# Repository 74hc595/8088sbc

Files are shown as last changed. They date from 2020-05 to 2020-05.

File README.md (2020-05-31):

# 8088 Single Board Computer

A minimal single-board computer based on the Intel 8088 processor.
That's the same processor used in the original IBM PC, but this is just a
simple project and doesn't strive for PC/DOS compatibility.



## Specs
- 8088 or compatible CPU in minimal mode (5 MHz with [8088](https://www.jameco.com/z/8088-Major-Brands-IC-8088-8-Bit-HMOS-MPU_52142.html), 8 MHz with 8088-2)
    - Clock oscillator at 3x frequency of CPU clock frequency. For 8 MHz operation, uses a [24 MHz half-can crystal oscillator](https://www.mouser.com/ProductDetail/ECS/ECS-2200B-240?qs=GxOUx7aO6nwQDraMtk%2FyHw%3D%3D)
- 1 MB static RAM (2x [AS6C4008-55PCN](https://www.mouser.com/ProductDetail/Alliance-Memory/AS6C4008-55PCN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))
- 32 KB ROM (1x [AT28C256-15](https://www.jameco.com/z/28C256-15-Major-Brands-IC-28C256-16-EEPROM-256K-Bit-CMOS-Parallel_74843.html))
- FTDI-compatible 5V serial port provided by a [16C550](https://www.jameco.com/shop/ProductDisplay?catalogId=10001&langId=-1&storeId=10001&productId=288809) UART (up to 115200 baud)
- 32 column by 4 row LED display (sixteen PDSP-1881 intelligent displays,
  display board schematic available [here](https://github.com/74hc595/kicad-intelligent-displays))
- Uses five common 74HC chips for glue logic (74HC4017, 74HC132, 74HC573,
  74HC75, 74HC139). Does not require any of the Intel 8200-series support chips.
- 5V power via USB-A connector

## Memory map

```
00000h-7FFFFh - RAM
80000h-FFFFFh - bankable (RAM, ROM, expansion 1, or expansion 2)
```

## I/O map

Only bits 7 and 8 are used for decoding.

```
000h-07Fh - I/O bank 0
    060h-067h - 16550 UART
080h-0FFh - I/O bank 1
100h-17Fh - I/O bank 2
    100h-107h - 128-character display (16x PDSP-1881 or similar)
180h-1FFh - I/O bank 3
```

More info on display decoding:

```
100h-17Fh - Flash RAM
900h-97Fh - UDC Address Register
B00h-B7Fh - UDC RAM
D00h-D7Fh - Control Word Register
F00h-F7Fh - Character RAM
```

## Bank switching and input/output

The modem control lines of the 16550 UART are used as general purpose input and
output lines.

```
~OUT1 - bank select bit 0
~OUT2 - bank select bit 1
~DTR  - general purpose output 0 (LED2)
~RTS  - general purpose output 1 (LED3)
~RI   - general purpose input 0
~DCD  - general purpose input 1
~DSR  - general purpose input 2
~CTS  - general purpose input 3
```

Bank select bits 0 and 1 control which device is mapped into the upper half of
the address space:

```
00 - expansion 1
01 - expansion 2
10 - RAM
11 - ROM (default at power-up)
```

These are controlled by bits 2 and 3 of the 16550's Modem Control Register.
(`64h`)

## Interrupts

The four general-purpose inputs can be set up as inputs by configuring the
16550's Interrupt Enable Register (`61h`). However, this won't be very useful
because the 8088's `~INTA` line is not connected to anything, so when an
interrupt is received, there is no device to place the vector number on the data
bus.

Pressing the `NMI` button will generate a non-maskable interrupt (`INT 04h`).
The button is debounced in hardware.

## Software

Not much here, just enough to test memory and dump the register state. Compiles
with NASM (version 2.14.02 used). Running `make` in the `code/` directory
generates as 32KB binary file. Running `make flash` can be used to burn the
ROM image to an AT28C256 EEPROM chip using a [MiniPro TL866II+](https://www.amazon.com/tl866ii-plus/s?k=tl866ii+plus)
with the [minipro](https://gitlab.com/DavidGriffith/minipro/) utility.

(The TL866II+ is around $60 USD and widely available, if you don't have one,
you should get one!)

1. Power LED will light up.
2. `OUT1` LED will blink four times. (Testing 8 segments of lower RAM)
3. `OUT0` will light.
4. `OUT1` LED will blink four times. (Testing 8 segments of upper RAM)
5. `Hello 8088!` will be printed to the serial port. (115200 8N1)
6. `OUT0` and `OUT1` LEDs will toggle with 50% duty cycle. (verify with scope)
7. Pressing the `NMI` button will print the register state:

```
AX=F001 CS=F000 IP=82E0      NMI
BX=FFF0 DS=F000 SI=82F5     --I-
CX=0000 ES=0000 DI=0024 --------
DX=F202 SS=7000 SP=FFE6 BP=FFFF
```

### API

Interrupt vector `06h` points to the character output routine. If using the
PDSP-1881 LED display, this can be changed to `disp_outch_int` to write to the
display instead of the serial port.

`INT 07h` prints the null-terminated string in `CS:SI`.

`INT 08h` is a rudimentary formatted-output routine. See `output.inc`.

## Future work

Probably none. This was just a quick project and I probably won't work on it
long-term because... honestly, I'm just not a fan of 8086 assembly language and
its weird 16-bit segmented model. Mainly, I had these chips lying around and
wanted to do something with them.

## About

Open hardware, released under the terms of the 3-clause BSD license.

Copyright 2020 Matt Sarnoff.

http://twitter.com/txsector

http://msarnoff.org

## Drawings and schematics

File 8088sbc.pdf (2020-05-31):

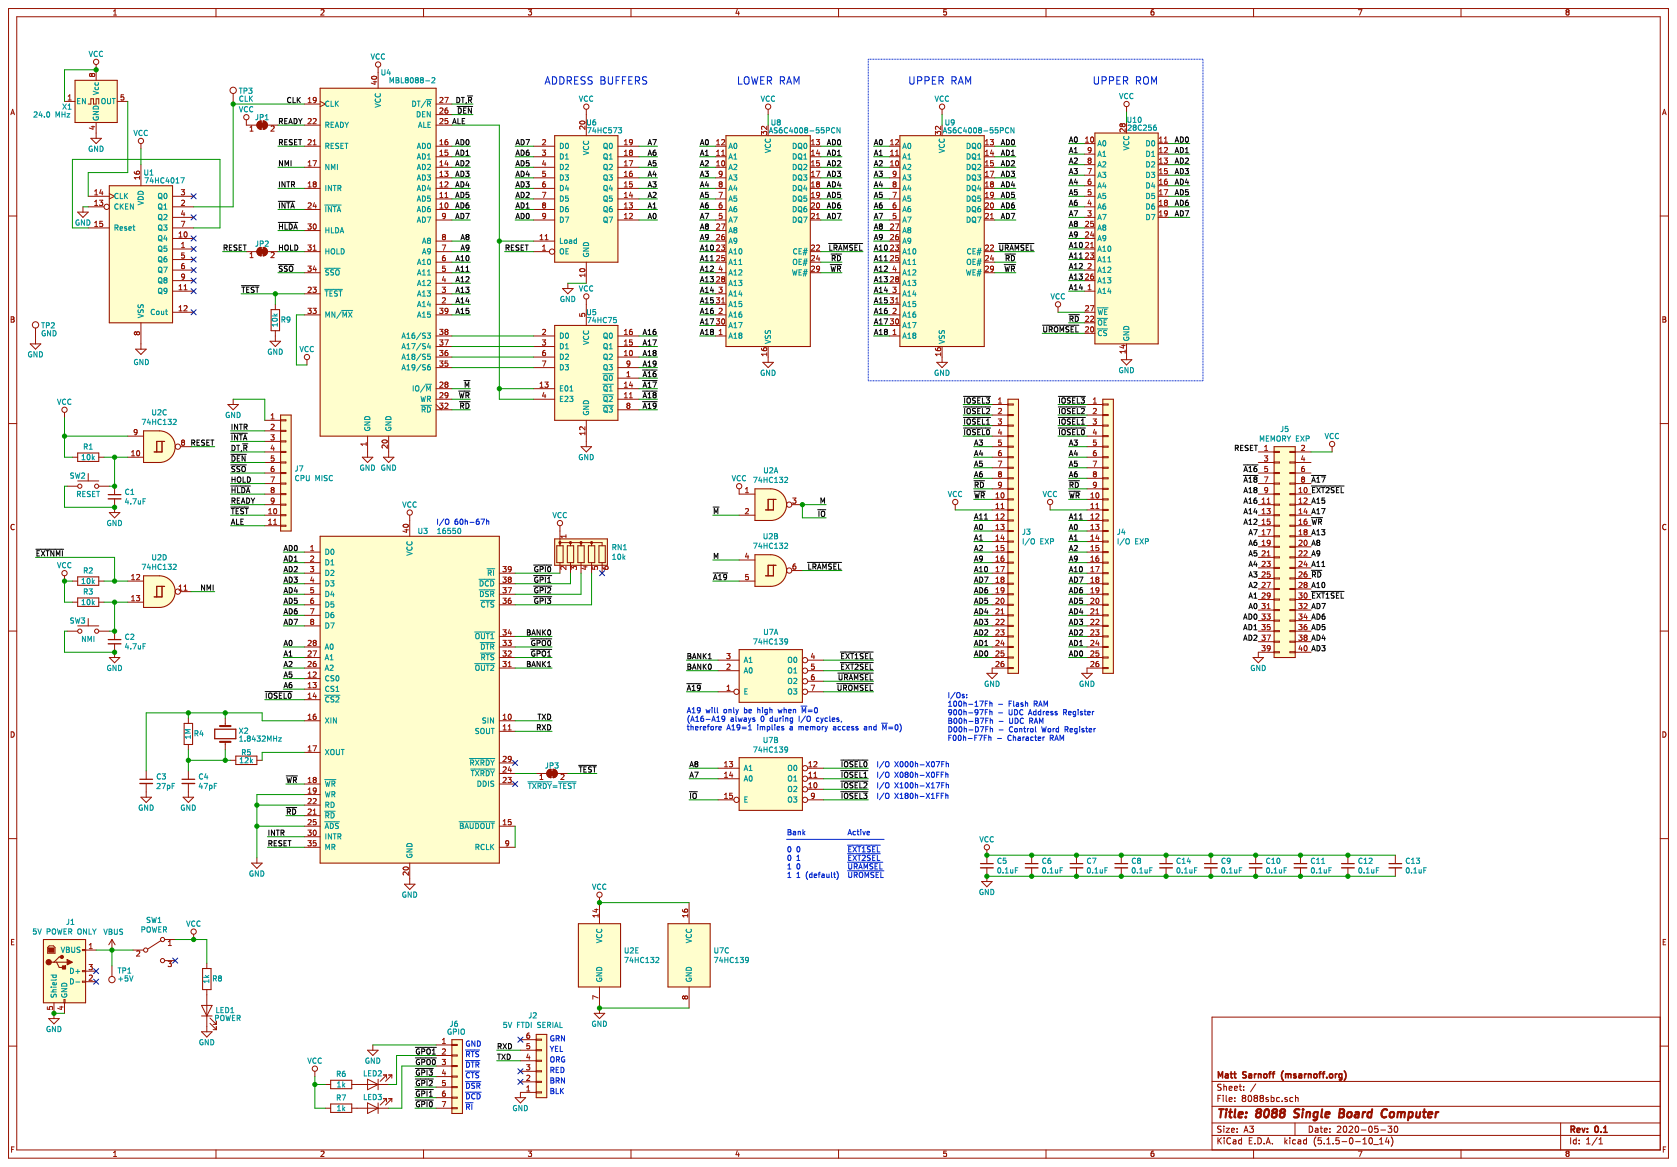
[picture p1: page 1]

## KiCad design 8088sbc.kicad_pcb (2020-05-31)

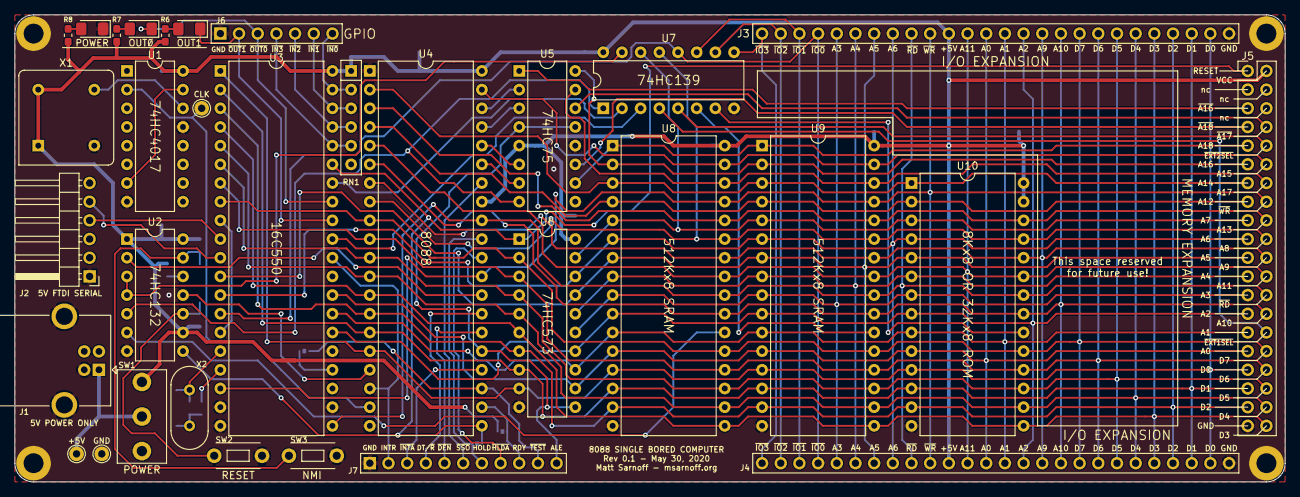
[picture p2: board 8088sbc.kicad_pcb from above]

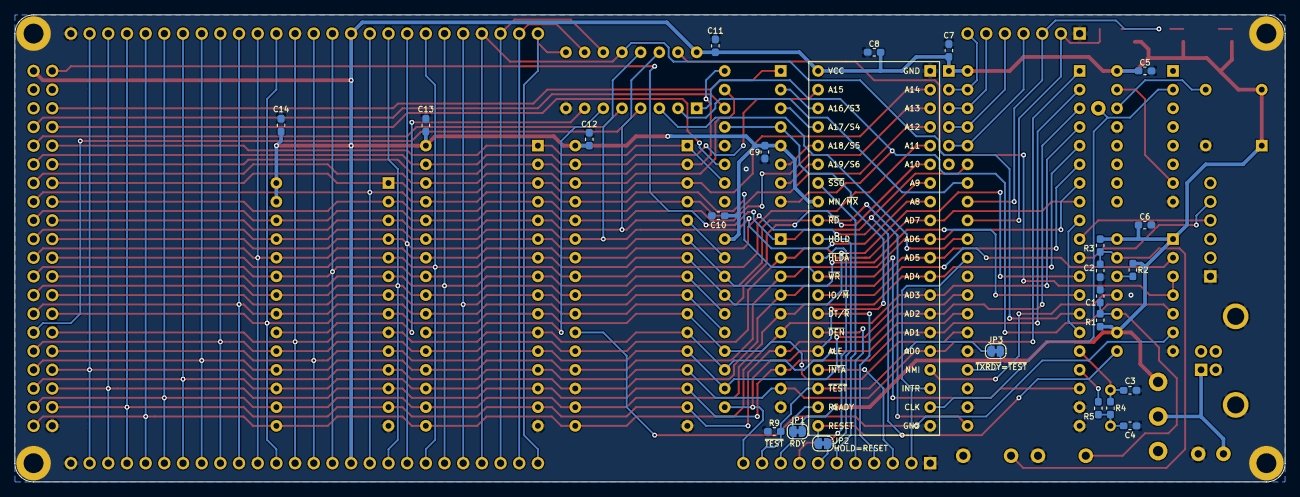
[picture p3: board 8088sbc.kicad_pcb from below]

Board: 2 copper layers, 172.7 x 63.5 mm, 55 parts (23 on the bottom side), 87 nets.

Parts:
C1, C2: 4.7uF; R_0603_1608Metric_Pad1.05x0.95mm_HandSolder
C3: 27pF; C_0603_1608Metric_Pad1.05x0.95mm_HandSolder
C4: 47pF; C_0603_1608Metric_Pad1.05x0.95mm_HandSolder
C5, C6, C7, C8, C9, C10, C11, C12, C13, C14: 0.1uF; C_0603_1608Metric_Pad1.05x0.95mm_HandSolder
J1: 5V POWER ONLY; USB_B_OST_USB-B1HSxx_Horizontal
J2: 5V FTDI SERIAL; PinHeader_1x06_P2.54mm_Horizontal
J3, J4: I/O EXP; PinHeader_1x26_P2.54mm_Vertical
J5: MEMORY EXP; PinHeader_2x20_P2.54mm_Vertical
J6: GPIO; PinHeader_1x07_P2.54mm_Vertical
J7: CPU MISC; PinHeader_1x11_P2.54mm_Vertical
JP1, JP2, JP3: SolderJumper_2_Bridged; SolderJumper-2_P1.3mm_Bridged_RoundedPad1.0x1.5mm
LED1: POWER; LED_1206_3216Metric_Pad1.42x1.75mm_HandSolder
LED2: OUT1; LED_1206_3216Metric_Pad1.42x1.75mm_HandSolder
LED3: OUT0; LED_1206_3216Metric_Pad1.42x1.75mm_HandSolder
R1, R2, R3, R9: 10k; R_0603_1608Metric_Pad1.05x0.95mm_HandSolder
R4: 1M; R_0603_1608Metric_Pad1.05x0.95mm_HandSolder
R5: 12k; R_0603_1608Metric_Pad1.05x0.95mm_HandSolder
R6, R7, R8: 330; R_0603_1608Metric_Pad1.05x0.95mm_HandSolder
RN1: 10k; R_Array_SIP6
SW1: POWER; SW_Slide_1P2T_Cylewet_ CYT1107
SW2: RESET; SW_PUSH_3x6mm
SW3: NMI; SW_PUSH_3x6mm
TP1: +5V; TestPoint_THTPad_D2.0mm_Drill1.0mm
TP2: GND; TestPoint_THTPad_D2.0mm_Drill1.0mm
TP3: CLK; TestPoint_THTPad_D2.0mm_Drill1.0mm
U1: 74HC4017; DIP-16_W7.62mm
U2: 74HC132; DIP-14_W7.62mm
U3: 16550; DIP-40_W15.24mm
U4: MBL8088-2; DIP-40_W15.24mm
U5: 74HC75; DIP-16_W7.62mm
U6: 74HC573; DIP-20_W7.62mm
U7: 74HC139; DIP-16_W7.62mm
U8, U9: AS6C4008-55PCN; DIP-32_W15.24mm
U10: 28C256; DIP-28_W15.24mm
X1: 20.0 MHz; Oscillator_DIP-8
X2: 1.8432MHz; Crystal_HC49-U_Vertical

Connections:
/A0: J3.13, J4.13, J5.31, U3.28, U6.12, U8.12, U9.12, U10.10
/A1: J3.14, J4.14, J5.29, U3.27, U6.13, U8.11, U9.11, U10.9
/A2: J3.15, J4.15, J5.27, U3.26, U6.14, U8.10, U9.10, U10.8
/A3: J3.5, J4.5, J5.25, U6.15, U8.9, U9.9, U10.7
/A4: J3.6, J4.6, J5.23, U6.16, U8.8, U9.8, U10.6
/A5: J3.7, J4.7, J5.21, U3.12, U6.17, U8.7, U9.7, U10.5
/A6: J3.8, J4.8, J5.19, U3.13, U6.18, U8.6, U9.6, U10.4
/A7: J5.17, U6.19, U7.14, U8.5, U9.5, U10.3
/A8: J5.20, U4.8, U7.13, U8.27, U9.27, U10.25
/A9: J3.16, J4.16, J5.22, U4.7, U8.26, U9.26, U10.24
/A10: J3.17, J4.17, J5.28, U4.6, U8.23, U9.23, U10.21
/A11: J3.12, J4.12, J5.24, U4.5, U8.25, U9.25, U10.23
/A12: J5.15, U4.4, U8.4, U9.4, U10.2
/A13: J5.18, U4.3, U8.28, U9.28, U10.26
/A14: J5.13, U4.2, U8.3, U9.3, U10.1
/A15: J5.12, U4.39, U8.31, U9.31
/A16: J5.11, U5.16, U8.2, U9.2
/A17: J5.14, U5.15, U8.30, U9.30
/A18: J5.9, U5.10, U8.1, U9.1
/AD0: J3.25, J4.25, J5.33, U3.1, U4.16, U6.9, U8.13, U9.13, U10.11
/AD1: J3.24, J4.24, J5.35, U3.2, U4.15, U6.8, U8.14, U9.14, U10.12
/AD2: J3.23, J4.23, J5.37, U3.3, U4.14, U6.7, U8.15, U9.15, U10.13
/AD3: J3.22, J4.22, J5.40, U3.4, U4.13, U6.6, U8.17, U9.17, U10.15
/AD4: J3.21, J4.21, J5.38, U3.5, U4.12, U6.5, U8.18, U9.18, U10.16
/AD5: J3.20, J4.20, J5.36, U3.6, U4.11, U6.4, U8.19, U9.19, U10.17
/AD6: J3.19, J4.19, J5.34, U3.7, U4.10, U6.3, U8.20, U9.20, U10.18
/AD7: J3.18, J4.18, J5.32, U3.8, U4.9, U6.2, U8.21, U9.21, U10.19
/ALE: J7.11, U4.25, U5.4, U5.13, U6.11
/BANK0: U3.34, U7.2
/BANK1: U3.31, U7.3
/CLK: TP3.1, U1.2, U4.19
/DT,~R: J7.4, U4.27
/HOLD: J7.7, JP2.2, U4.31
/INTR: J7.2, U3.30, U4.18
/M: U2.3, U2.4, U7.15
/NMI: U2.11, U4.17
/READY: J7.9, JP1.2, U4.22
/RESET: J5.1, JP2.1, U2.8, U3.35, U4.21, U6.1
/RXD: J2.5, U3.11
/TXD: J2.4, U3.10
/~A16: J5.5, U5.1
/~A17: J5.8, U5.14
/~A18: J5.7, U5.11
/~A19: U2.5, U5.8, U7.1
/~DEN: J7.5, U4.26
/~EXT1SEL: J5.30, U7.4
/~EXT2SEL: J5.10, U7.5
/~EXTNMI: R2.1, U2.12
/~GPI0: J6.7, RN1.2, U3.39
/~GPI1: J6.6, RN1.3, U3.38
/~GPI2: J6.5, RN1.4, U3.37
/~GPI3: J6.4, RN1.5, U3.36
/~GPO0: J6.3, LED3.1, U3.33
/~GPO1: J6.2, LED2.1, U3.32
/~HLDA: J7.8, U4.30
/~INTA: J7.3, U4.24
/~IOSEL0: J3.4, J4.4, U3.14, U7.12
/~IOSEL1: J3.3, J4.3, U7.11
/~IOSEL2: J3.2, J4.2, U7.10
/~IOSEL3: J3.1, J4.1, U7.9
/~LRAMSEL: U2.6, U8.22
/~M: U2.2, U4.28
/~RD: J3.9, J4.9, J5.26, U3.21, U4.32, U8.24, U9.24, U10.22
/~SSO: J7.6, U4.34
/~TEST: J7.10, JP3.2, R9.2, U4.23
/~URAMSEL: U7.6, U9.22
/~UROMSEL: U7.7, U10.20
/~WR: J3.10, J4.10, J5.16, U3.18, U4.29, U8.29, U9.29
GND: C1.2, C2.2, C3.2, C4.2, C5.2, C6.2, C7.2, C8.2, C9.2, C10.2, C11.2, C12.2, C13.2, C14.2, J1.4, J1.5, J2.1, J3.26, J4.26, J5.39, J6.1, J7.1, LED1.1, R9.1, SW2.1, SW3.1, TP2.1, U1.8, U1.13, U2.7, U3.19, U3.20, U3.22, U3.25, U4.1, U4.20, U5.12, U6.10, U7.8, U8.16, U9.16, U10.14, X1.4
unnamed: C1.1, R1.1, SW2.2, U2.10
unnamed: C2.1, R3.1, SW3.2, U2.13
unnamed: C3.1, R4.2, U3.16, X2.2
unnamed: C4.1, R4.1, R5.2, X2.1
unnamed: JP3.1, U3.24
unnamed: LED1.2, R8.1
unnamed: LED2.2, R6.1
unnamed: LED3.2, R7.1
unnamed: R5.1, U3.17
unnamed: U1.14, X1.5
unnamed: U1.7, U1.15
unnamed: U3.9, U3.15
unnamed: U4.35, U5.7
unnamed: U4.36, U5.6
unnamed: U4.37, U5.3
unnamed: U4.38, U5.2
VBUS: J1.1, SW1.2, TP1.1
VCC: C5.1, C6.1, C7.1, C8.1, C9.1, C10.1, C11.1, C12.1, C13.1, C14.1, J3.11, J4.11, J5.2, JP1.1, R1.2, R2.2, R3.2, R6.2, R7.2, R8.2, RN1.1, SW1.1, U1.16, U2.1, U2.9, U2.14, U3.40, U4.33, U4.40, U5.5, U6.20, U7.16, U8.32, U9.32, U10.27, U10.28, X1.1, X1.8
